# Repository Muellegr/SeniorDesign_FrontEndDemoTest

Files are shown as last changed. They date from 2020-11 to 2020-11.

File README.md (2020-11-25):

# SeniorDesign_FrontEndDemoTest
OSU Senior Design to demonstrate a working, very low quality front end for an oscilloscope.  
The focus of this is to test a basic fully differential op amp and applying a DC offset to the output.  
* Selectable AC or DC mode
* 5 different attenuation amounts from 1x to 20x
* Impedance matchedish to 50ohm
* Adjustable DC offset for testing from -5v to +5v
-------

Due to being used in a presentation assignment I put a lot of focus on cleary seperating system blocks at the cost of longer signal traces and effeciant layouts.  
A 4 layer board was chosen for ease of life and some signal quality. The back plane is nearly unused excluding some very minor power routing below the differential op amp.

[ Bill of Materials! ]( https://github.com/Muellegr/SeniorDesign_FrontEndDemoTest/wiki )

Schematic and all PCB layers can be found in the Schematics folder.  
* [ Schematic ]( https://raw.githubusercontent.com/Muellegr/SeniorDesign_FrontEndDemoTest/main/Front_End_Kicad/Schematics/Front_End_Kicad.pdf )
* [ Signals - Layer 1 ]( https://raw.githubusercontent.com/Muellegr/SeniorDesign_FrontEndDemoTest/main/Front_End_Kicad/Schematics/Front_End_Kicad-F_Cu.pdf )
* [ GND Plane - Layer 2]( https://raw.githubusercontent.com/Muellegr/SeniorDesign_FrontEndDemoTest/main/Front_End_Kicad/Schematics/Front_End_Kicad-in1_Cu.pdf )

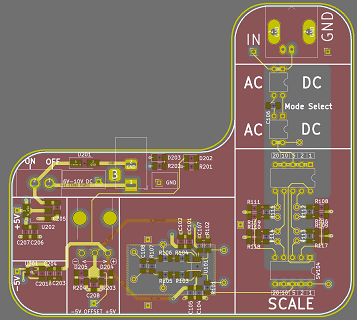
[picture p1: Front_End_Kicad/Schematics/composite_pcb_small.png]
neat!
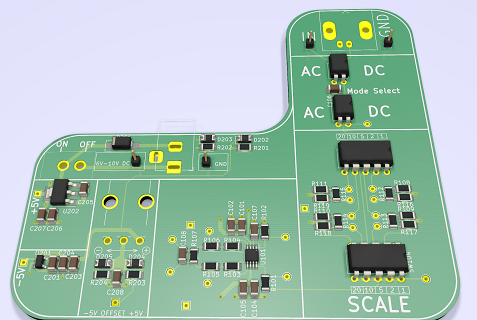
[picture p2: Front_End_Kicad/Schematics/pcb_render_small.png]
Look at you! Reading images and stuff!


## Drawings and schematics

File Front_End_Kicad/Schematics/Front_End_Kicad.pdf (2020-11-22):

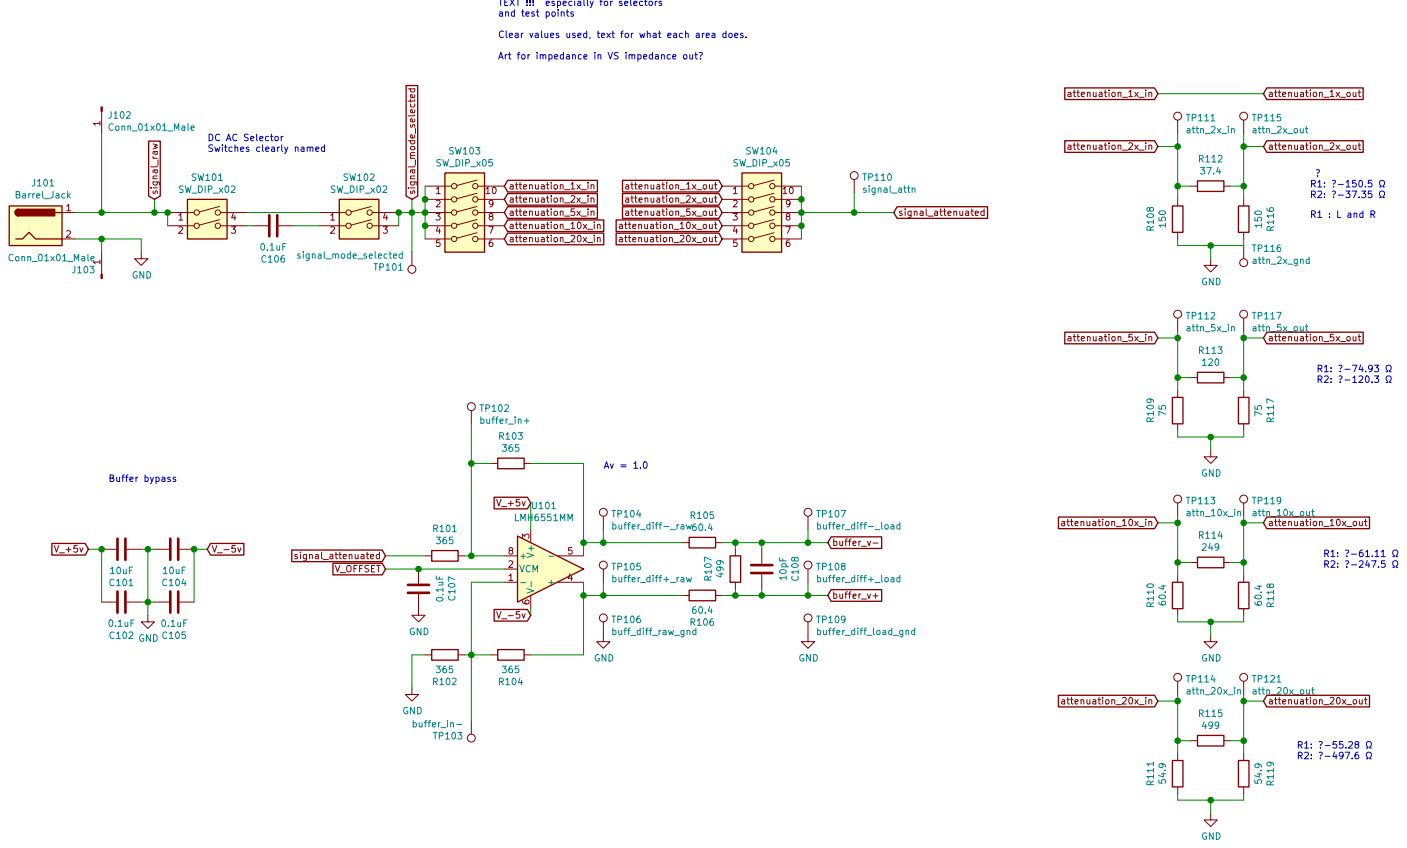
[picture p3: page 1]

TEXT !!! especially for selectors

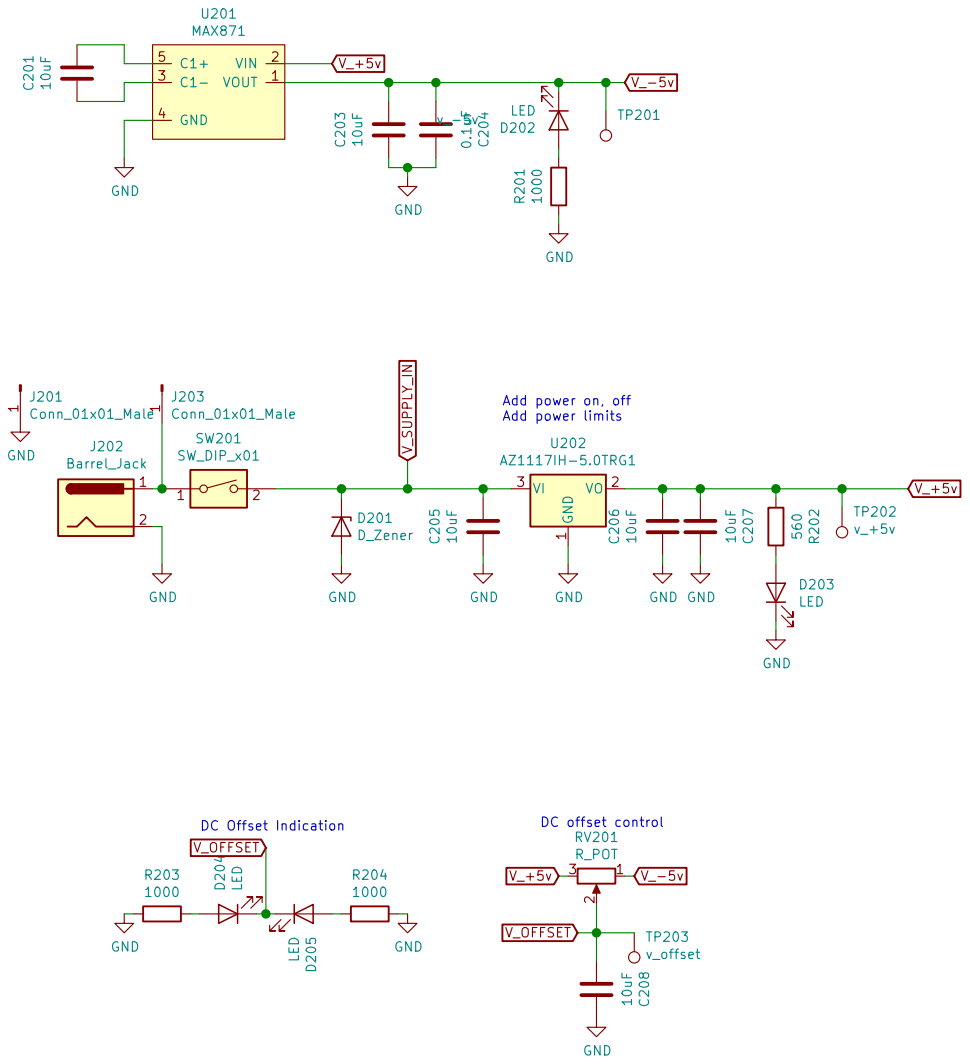
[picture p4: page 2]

DC offset control Add power on, off

Add power limits DC Offset Indication

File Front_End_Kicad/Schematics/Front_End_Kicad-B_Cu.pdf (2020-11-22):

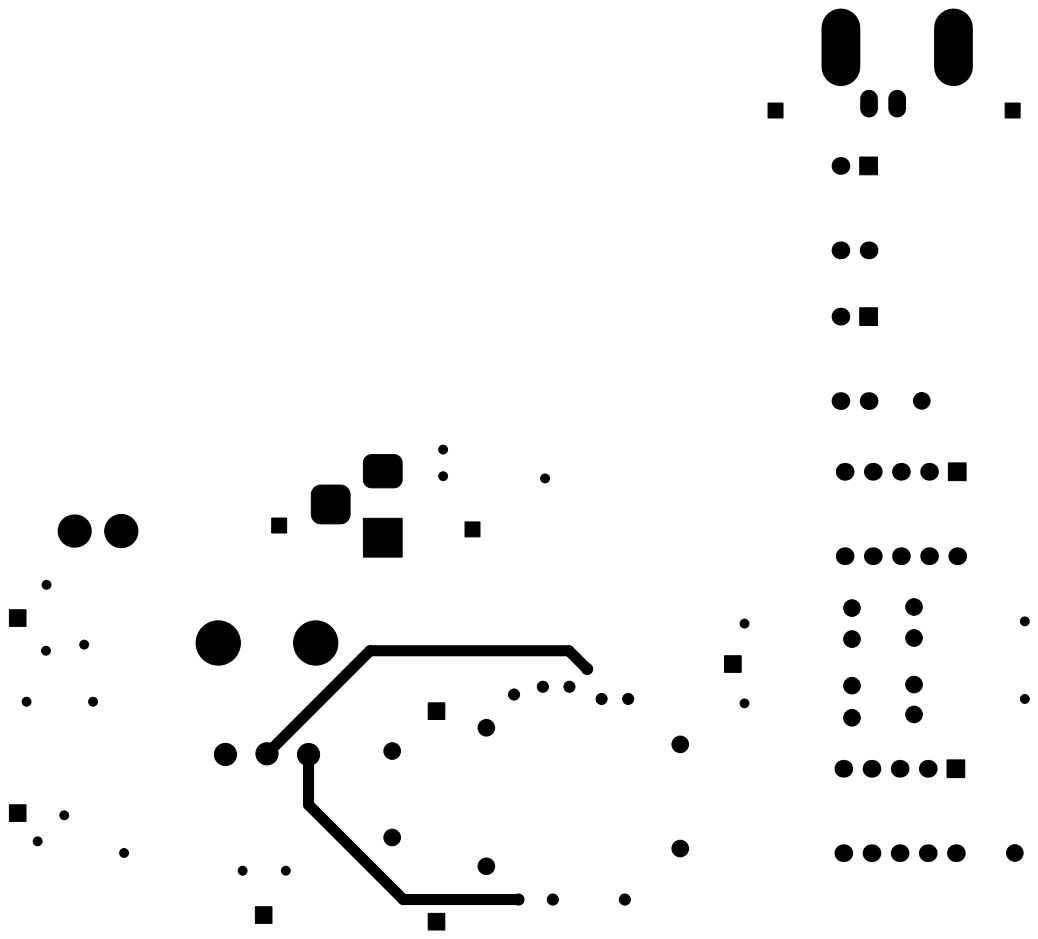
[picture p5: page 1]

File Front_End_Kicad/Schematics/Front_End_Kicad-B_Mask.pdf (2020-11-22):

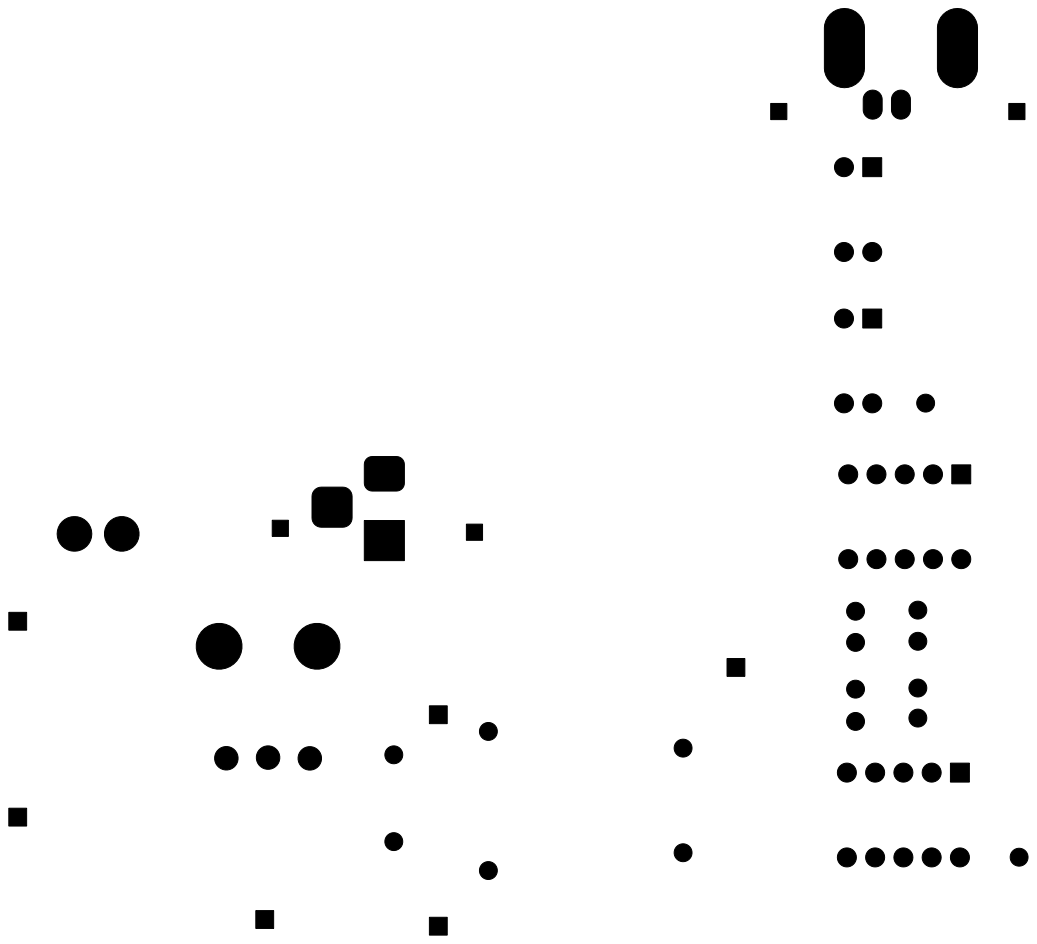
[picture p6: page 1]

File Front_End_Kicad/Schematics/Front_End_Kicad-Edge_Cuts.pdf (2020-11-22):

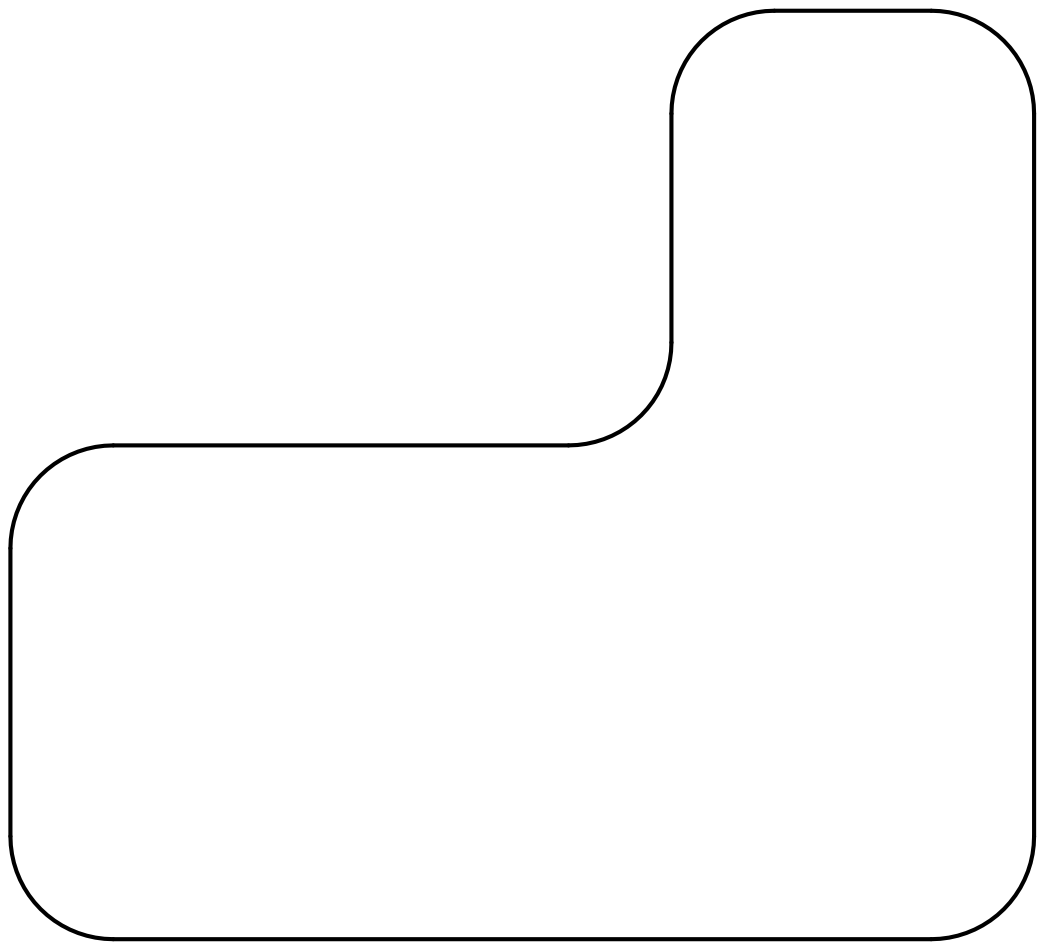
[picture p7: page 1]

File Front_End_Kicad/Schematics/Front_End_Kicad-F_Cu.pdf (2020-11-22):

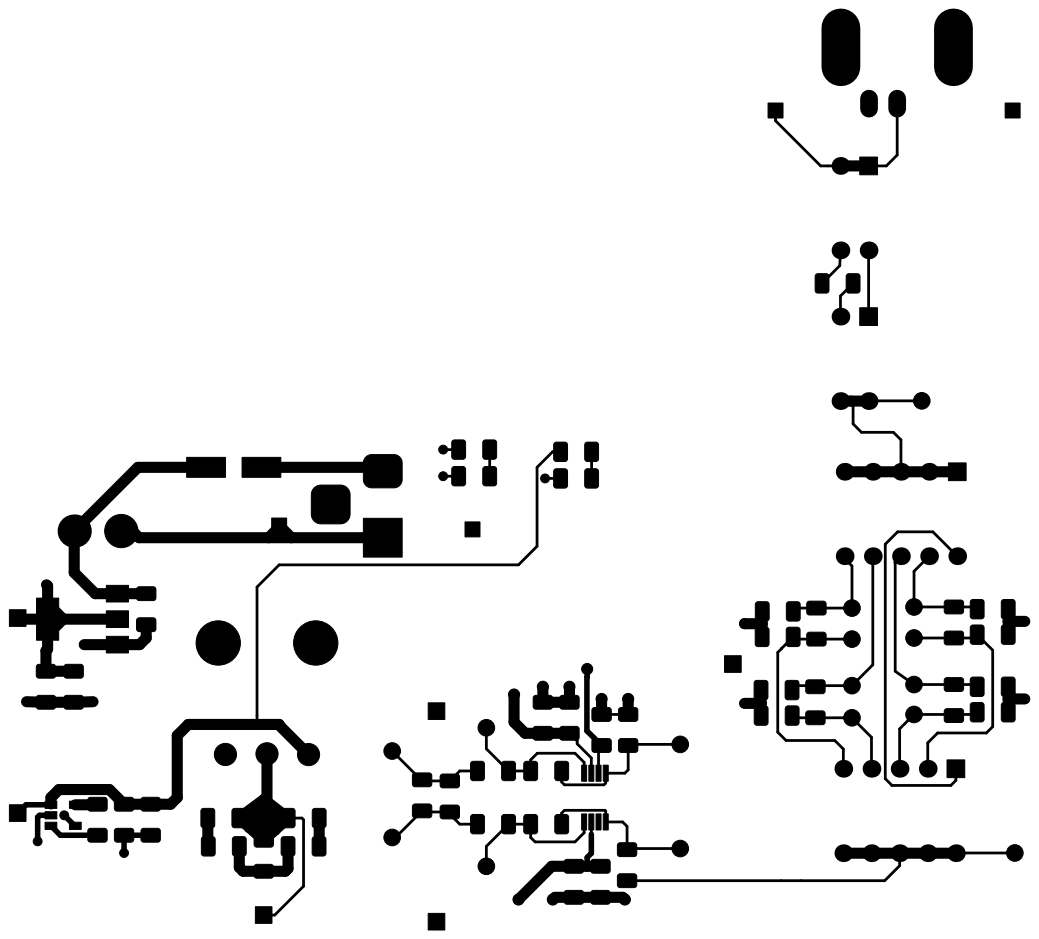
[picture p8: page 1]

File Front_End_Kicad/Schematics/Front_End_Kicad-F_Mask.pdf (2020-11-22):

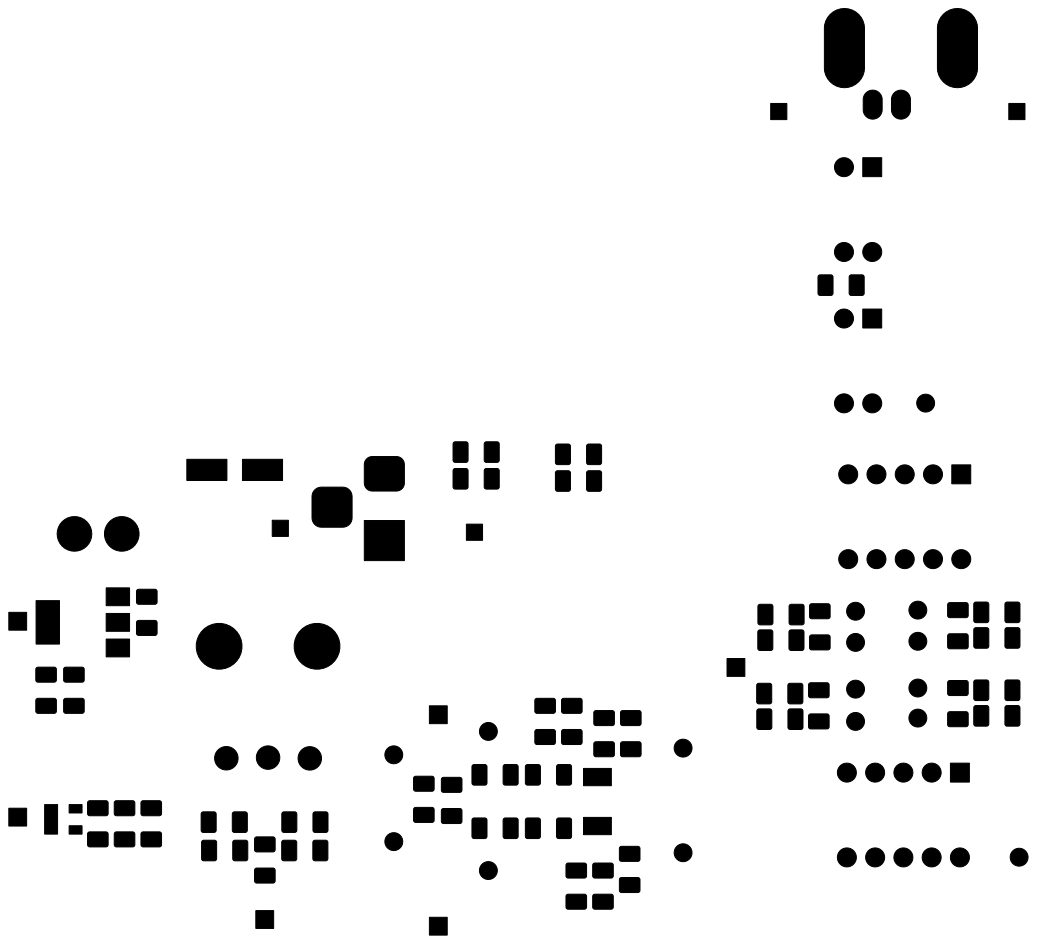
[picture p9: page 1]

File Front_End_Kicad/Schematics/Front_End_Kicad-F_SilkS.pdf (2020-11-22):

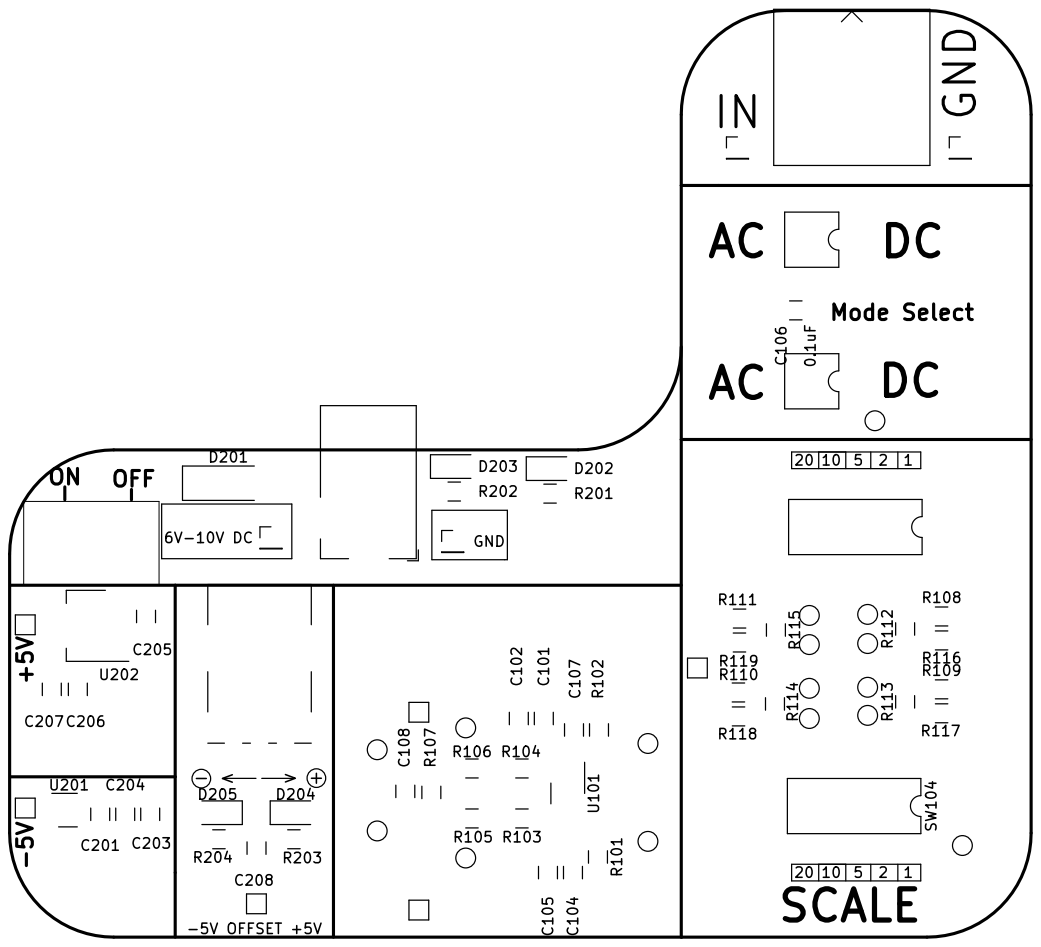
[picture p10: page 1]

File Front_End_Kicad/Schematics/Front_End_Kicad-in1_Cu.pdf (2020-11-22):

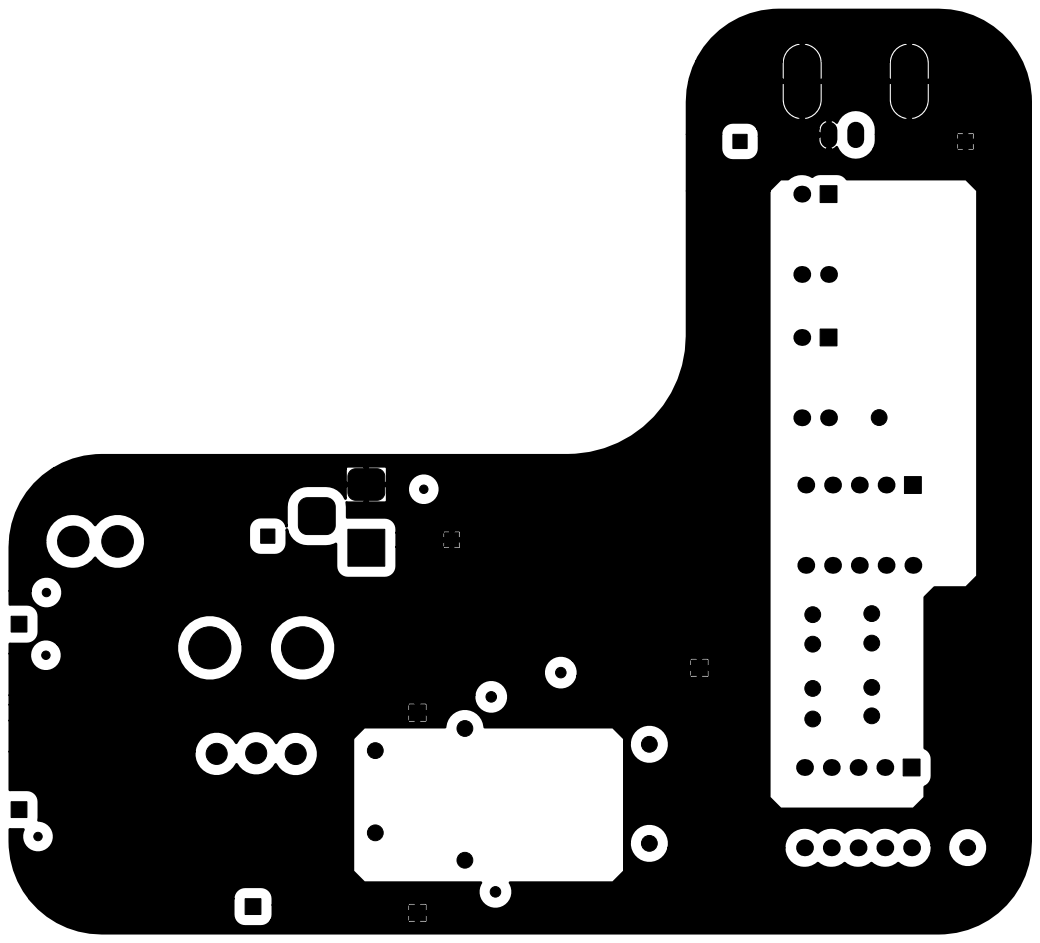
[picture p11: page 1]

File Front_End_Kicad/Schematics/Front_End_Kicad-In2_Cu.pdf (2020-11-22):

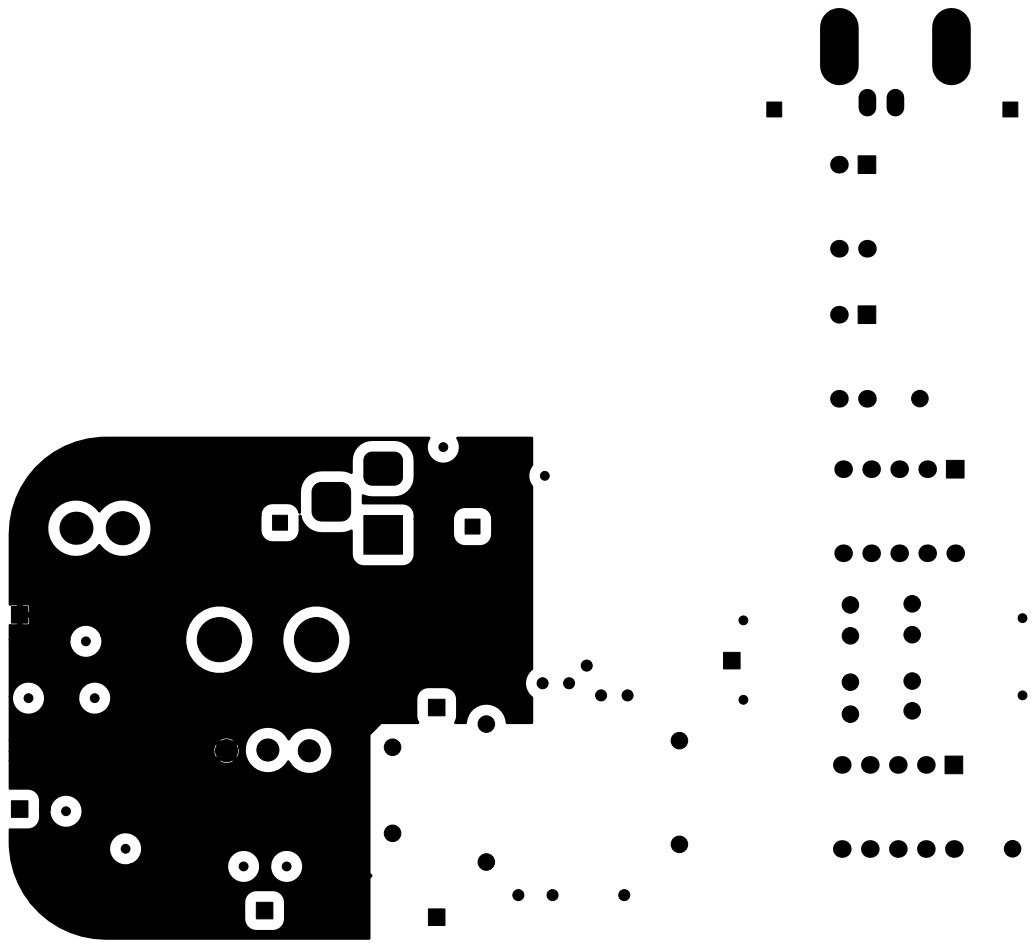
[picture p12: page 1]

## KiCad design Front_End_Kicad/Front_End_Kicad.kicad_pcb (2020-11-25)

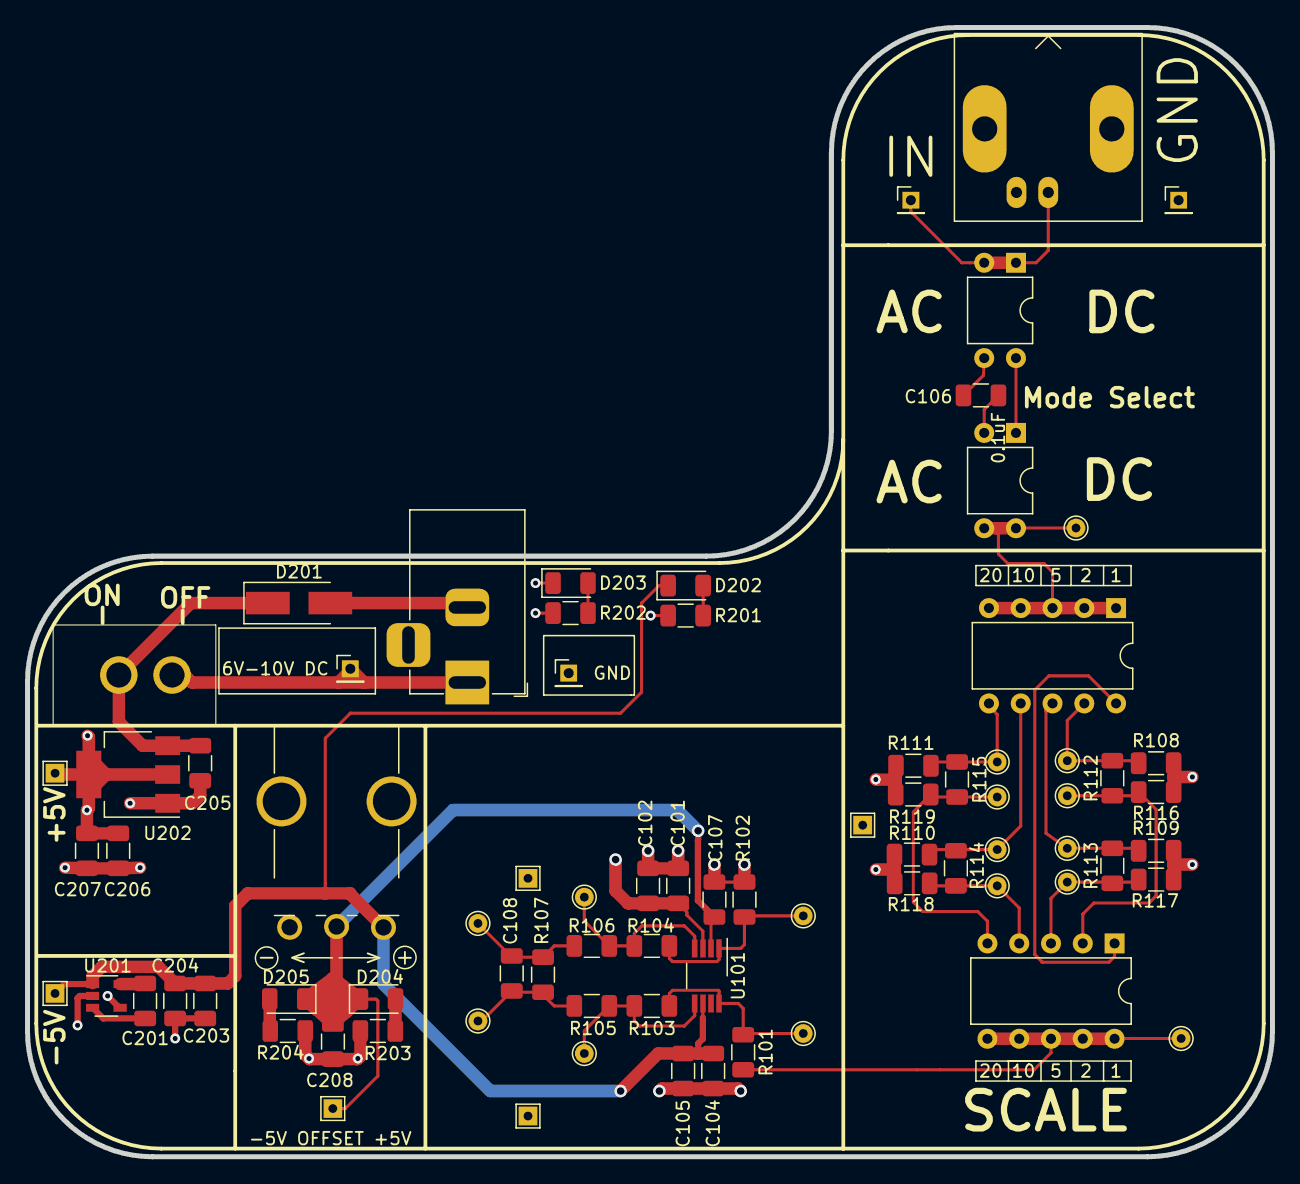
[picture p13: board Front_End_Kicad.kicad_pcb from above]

Board: 4 copper layers, 99.5 x 90.2 mm, 79 parts (0 on the bottom side), 33 nets.

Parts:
C101, C104, C201, C203, C205, C206, C207, C208: 10uF; C_1206_3216Metric
C102, C105, C106, C107, C204: 0.1uF; C_1206_3216Metric
C108: 10pF; C_1206_3216Metric
D201: D_Zener; D_SMA_Handsoldering
D202, D203, D204, D205: LED; D_1206_3216Metric
J101: Barrel_Jack; BNC_Amphenol_B6252HB-NPP3G-50_Horizontal
J102, J103, J201, J203: Conn_01x01_Male; PinHeader_1x01_P2.00mm_Vertical
J202: Barrel_Jack; BarrelJack_Horizontal
R101, R102, R103, R104: 365; R_1206_3216Metric
R105, R106, R110, R118: 60.4; R_1206_3216Metric
R107, R115: 499; R_1206_3216Metric
R108, R116: 150; R_1206_3216Metric
R109, R117: 75; R_1206_3216Metric
R111, R119: 54.9; R_1206_3216Metric
R112: 37.4; R_1206_3216Metric
R113: 120; R_1206_3216Metric
R114: 249; R_1206_3216Metric
R201, R203, R204: 1000; R_1206_3216Metric
R202: 560; R_1206_3216Metric
RV201: R_POT; Senior_Design_Front_End
SW101, SW102: SW_DIP_x02; DIP-4_W7.62mm
SW103, SW104: SW_DIP_x05; DIP-10_W7.62mm
SW201: SW_DIP_x01; front_end_power_toggle
TP101: signal_mode_selected; TestPoint_THTPad_D1.5mm_Drill0.7mm
TP102: buffer_in+; TestPoint_THTPad_D1.5mm_Drill0.7mm
TP103: buffer_in-; TestPoint_THTPad_D1.5mm_Drill0.7mm
TP104: buffer_diff-_raw; TestPoint_THTPad_D1.5mm_Drill0.7mm
TP105: buffer_diff+_raw; TestPoint_THTPad_D1.5mm_Drill0.7mm
TP106: buff_diff_raw_gnd; TestPoint_THTPad_1.5x1.5mm_Drill0.7mm
TP107: buffer_diff-_load; TestPoint_THTPad_D1.5mm_Drill0.7mm
TP108: buffer_diff+_load; TestPoint_THTPad_D1.5mm_Drill0.7mm
TP109: buffer_diff_load_gnd; TestPoint_THTPad_1.5x1.5mm_Drill0.7mm
TP110: signal_attn; TestPoint_THTPad_D1.5mm_Drill0.7mm
TP111: attn_2x_in; TestPoint_THTPad_D1.5mm_Drill0.7mm
TP112: attn_5x_in; TestPoint_THTPad_D1.5mm_Drill0.7mm
TP113: attn_10x_in; TestPoint_THTPad_D1.5mm_Drill0.7mm
TP114: attn_20x_in; TestPoint_THTPad_D1.5mm_Drill0.7mm
TP115: attn_2x_out; TestPoint_THTPad_D1.5mm_Drill0.7mm
TP116: attn_2x_gnd; TestPoint_THTPad_1.5x1.5mm_Drill0.7mm
TP117: attn_5x_out; TestPoint_THTPad_D1.5mm_Drill0.7mm
TP119: attn_10x_out; TestPoint_THTPad_D1.5mm_Drill0.7mm
TP121: attn_20x_out; TestPoint_THTPad_D1.5mm_Drill0.7mm
TP201: v_-5v; TestPoint_THTPad_1.5x1.5mm_Drill0.7mm
TP202: v_+5v; TestPoint_THTPad_1.5x1.5mm_Drill0.7mm
TP203: v_offset; TestPoint_THTPad_1.5x1.5mm_Drill0.7mm
U101: LMH6551MM; VSSOP-8_3.0x3.0mm_P0.65mm
U201: MAX871; SOT-23-5
U202: AZ1117IH-5.0TRG1; SOT-223-3_TabPin2

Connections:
GND: C101.1, C102.1, C104.2, C105.2, C107.2, C203.1, C204.2, C205.1, C206.1, C207.2, C208.2, D201.2, D203.1, J101.2, J103.1, J201.1, J202.2, R102.1, R108.2, R109.2, R110.2, R111.2, R116.1, R117.1, R118.1, R119.1, R201.2, R203.2, R204.1, TP106.1, TP109.1, TP116.1, U201.4, U202.1
unnamed: C106.1, SW102.2
unnamed: C106.2, SW101.3
unnamed: C201.1, U201.3
unnamed: C201.2, U201.5
unnamed: D202.2, R201.1
unnamed: D203.2, R202.1
unnamed: D204.2, R203.1
unnamed: D205.2, R204.2
unnamed: J202.1, J203.1, SW201.1
unnamed: R101.1, R103.2, TP102.1, U101.8
unnamed: R102.2, R104.1, TP103.1, U101.1
unnamed: R103.1, R105.2, TP104.1, U101.5
unnamed: R104.2, R106.1, TP105.1, U101.4
unnamed: SW101.4, SW102.1
V_+5v: C101.2, C102.2, C206.2, C207.1, R202.2, RV201.3, TP202.1, U101.3, U201.2, U202.2
V_-5v: C104.1, C105.1, C203.2, C204.1, D202.1, RV201.1, TP201.1, U101.6, U201.1
V_OFFSET: C107.1, C208.1, D204.1, D205.1, RV201.2, TP203.1, U101.2
V_SUPPLY_IN: C205.2, D201.1, SW201.2, U202.3
attenuation_1x_in: SW103.10, SW104.1
attenuation_2x_in: R108.1, R112.2, SW103.9, TP111.1
attenuation_2x_out: R112.1, R116.2, SW104.2, TP115.1
attenuation_5x_in: R109.1, R113.2, SW103.8, TP112.1
attenuation_5x_out: R113.1, R117.2, SW104.3, TP117.1
attenuation_10x_in: R110.1, R114.2, SW103.7, TP113.1
attenuation_10x_out: R114.1, R118.2, SW104.4, TP119.1
attenuation_20x_in: R111.1, R115.2, SW103.6, TP114.1
attenuation_20x_out: R115.1, R119.2, SW104.5, TP121.1
buffer_v+: C108.2, R106.2, R107.2, TP108.1
buffer_v-: C108.1, R105.1, R107.1, TP107.1
signal_attenuated: R101.2, SW104.6, SW104.7, SW104.8, SW104.9, SW104.10, TP110.1
signal_mode_selected: SW102.3, SW102.4, SW103.1, SW103.2, SW103.3, SW103.4, SW103.5, TP101.1
signal_raw: J101.1, J102.1, SW101.1, SW101.2

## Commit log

2020-10-27 Inital project setup with BoM included.
    [Front_End_Kicad.kicad_pcb, Front_End_Kicad.sch]
2020-11-17 Some work here and there. Opamp selected and 1 voltage driver selected.
    [Front_End_Kicad.sch]
2020-11-20 Split powre system off. Small devolopment with notes and layout.
    [Front_End_Kicad.sch, Front_End_Power.sch]
2020-11-20 Added footprints and digikey links to many of the components. Missing is the primary amplifier
    [Front_End_Kicad.sch, Front_End_Power.sch]
2020-11-21 All parts designed in schematic and preparing to enter PCB design
    [Front_End_Kicad.sch]
2020-11-21 Started work on PCB. Sections seperated and partially connected. Planning 4 layer
    [Front_End_Kicad.kicad_pcb, Front_End_Kicad.sch, Front_End_Power.sch]
2020-11-22 PCB nearly complete. Added schematics and layers
    [Front_End_Kicad.kicad_pcb, Front_End_Kicad.sch, Front_End_Power.sch]
2020-11-22 Added names to parts to show better
    [Front_End_Kicad.sch, Front_End_Power.sch]
2020-11-22 Revised PCB picure
2020-11-25 Updated schematic
    [Front_End_Kicad.kicad_pcb, Front_End_Kicad.sch, Front_End_Power.sch]
